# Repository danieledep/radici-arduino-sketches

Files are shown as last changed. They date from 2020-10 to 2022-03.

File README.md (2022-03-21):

# radici-arduino-sketches
arduino sketches, schematics and stl files for interactive physical audio installation

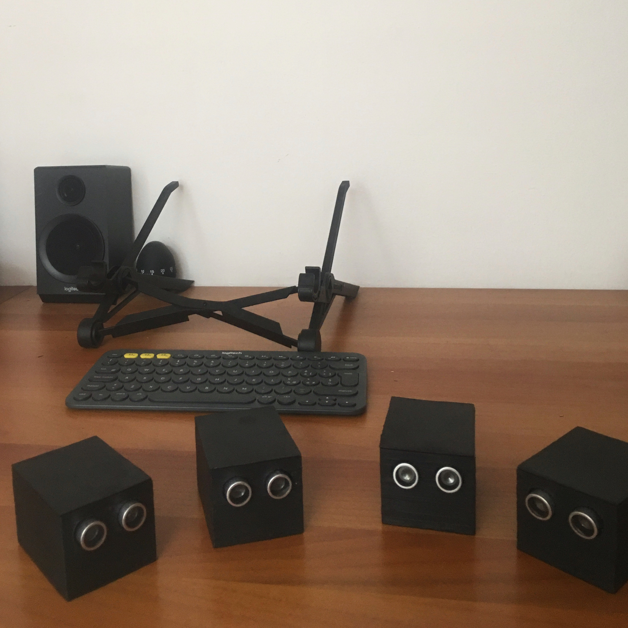
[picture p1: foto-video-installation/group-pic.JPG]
grouppic

*sensors group picture*

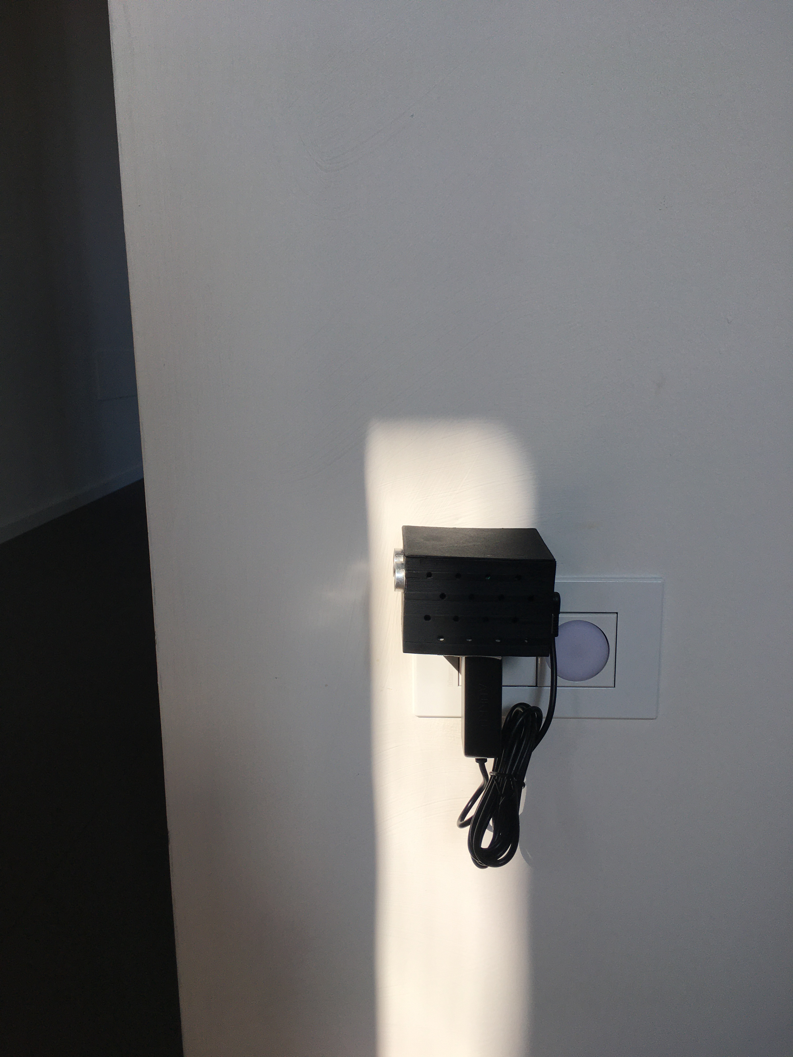
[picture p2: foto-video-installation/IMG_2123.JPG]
working sensor

*sensor at work patiently waiting for a trespass*   

The ```.wav``` sound effects are converted to data files with [wav2sketch](https://github.com/PaulStoffregen/Audio/tree/master/extras/wav2sketch) by Paul Stoffregen

## Libraries
- [RF24](https://github.com/nRF24/RF24)
- [SerialMP3Player](https://github.com/salvadorrueda/SerialMP3Player)
- [Teensy Audio Library](https://github.com/PaulStoffregen/Audio)
   
## Tutorials 
- [Getting Started with the HC-SR04 Ultrasonic sensor](https://create.arduino.cc/projecthub/Isaac100/getting-started-with-the-hc-sr04-ultrasonic-sensor-036380)
- [Simple nRF24L01+ 2.4GHz transceiver demo](https://forum.arduino.cc/index.php?topic=421081)  
- [Teensy Audio Tutorial Kit](https://www.pjrc.com/store/audio_tutorial_kit.html)
- [Instructions for using wav2sketch](https://forum.pjrc.com/threads/42401-Instructions-or-tutorials-for-using-wav2sketch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)
- [Feeding power to Arduino: the ultimate guide](https://www.open-electronics.org/the-power-of-arduino-this-unknown/)

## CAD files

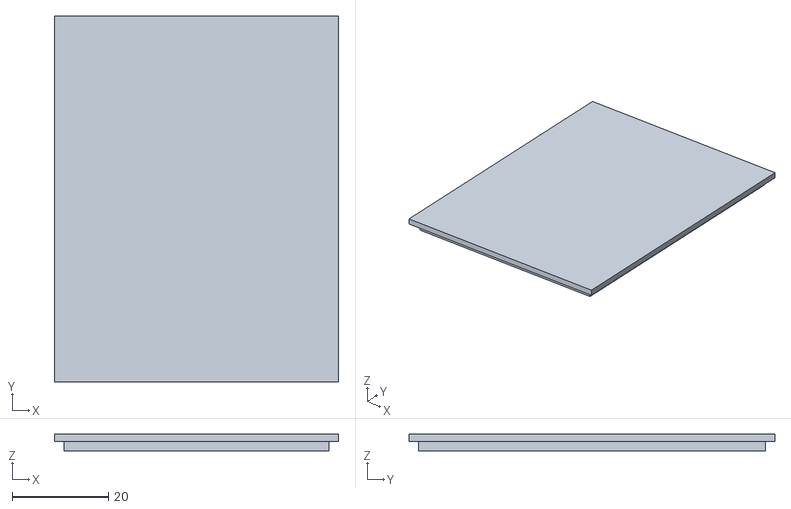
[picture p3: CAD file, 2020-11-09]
single-HCSR04-nRF24L01-tx/sensor-box-lid.stl
59.0 x 76.0 x 3.50

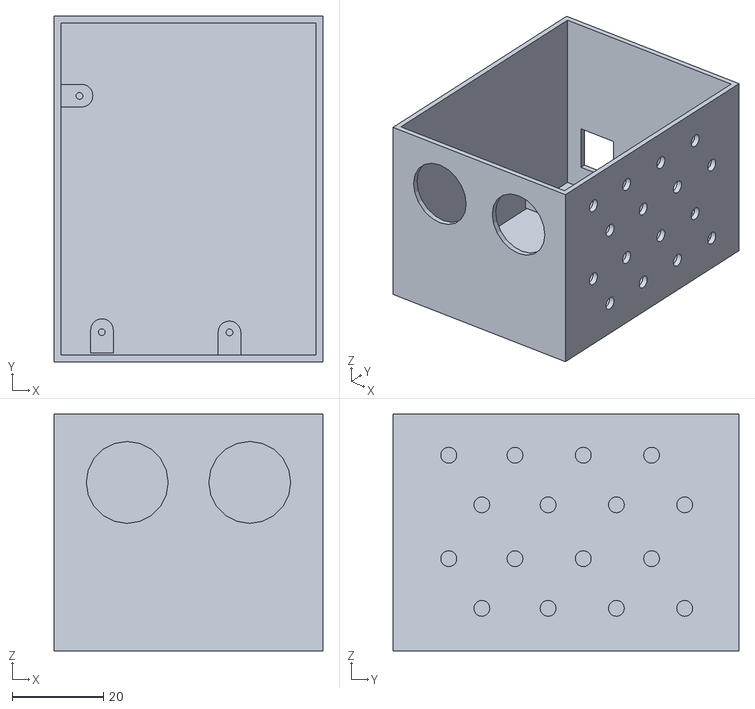
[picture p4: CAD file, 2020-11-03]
single-HCSR04-nRF24L01-tx/sensor-box.stl
59.0 x 76.0 x 52.0

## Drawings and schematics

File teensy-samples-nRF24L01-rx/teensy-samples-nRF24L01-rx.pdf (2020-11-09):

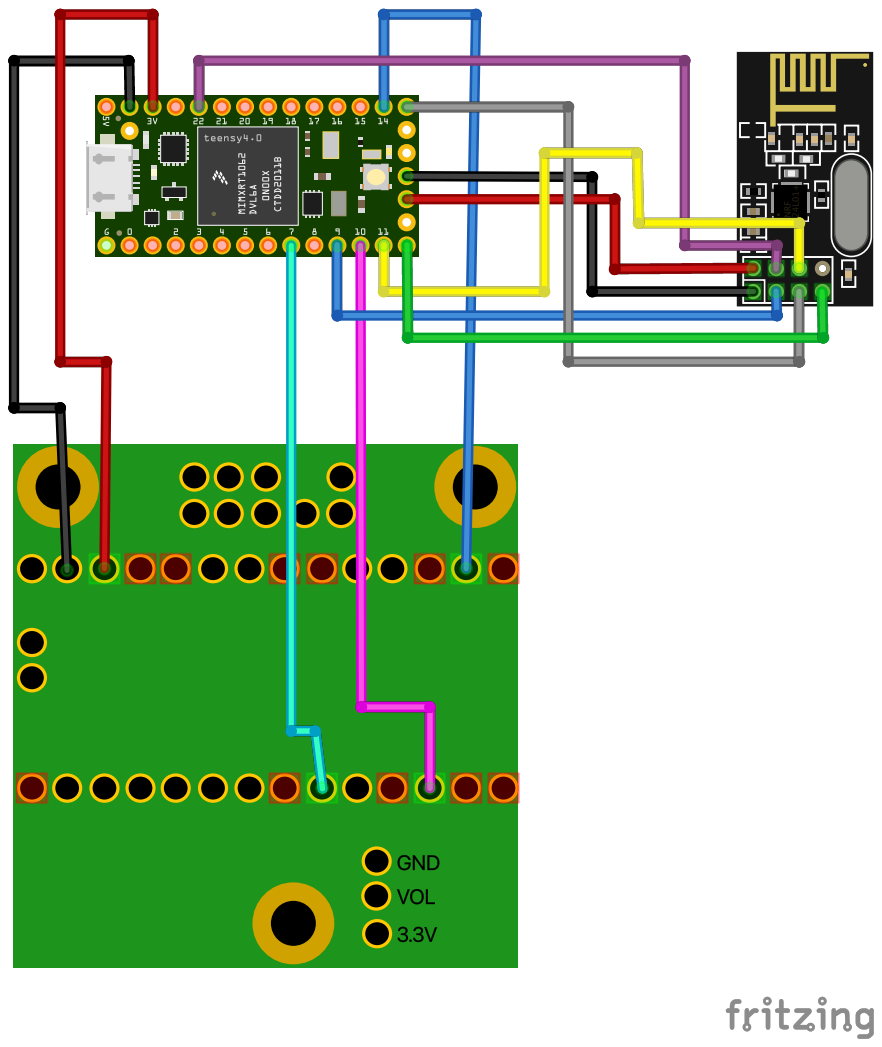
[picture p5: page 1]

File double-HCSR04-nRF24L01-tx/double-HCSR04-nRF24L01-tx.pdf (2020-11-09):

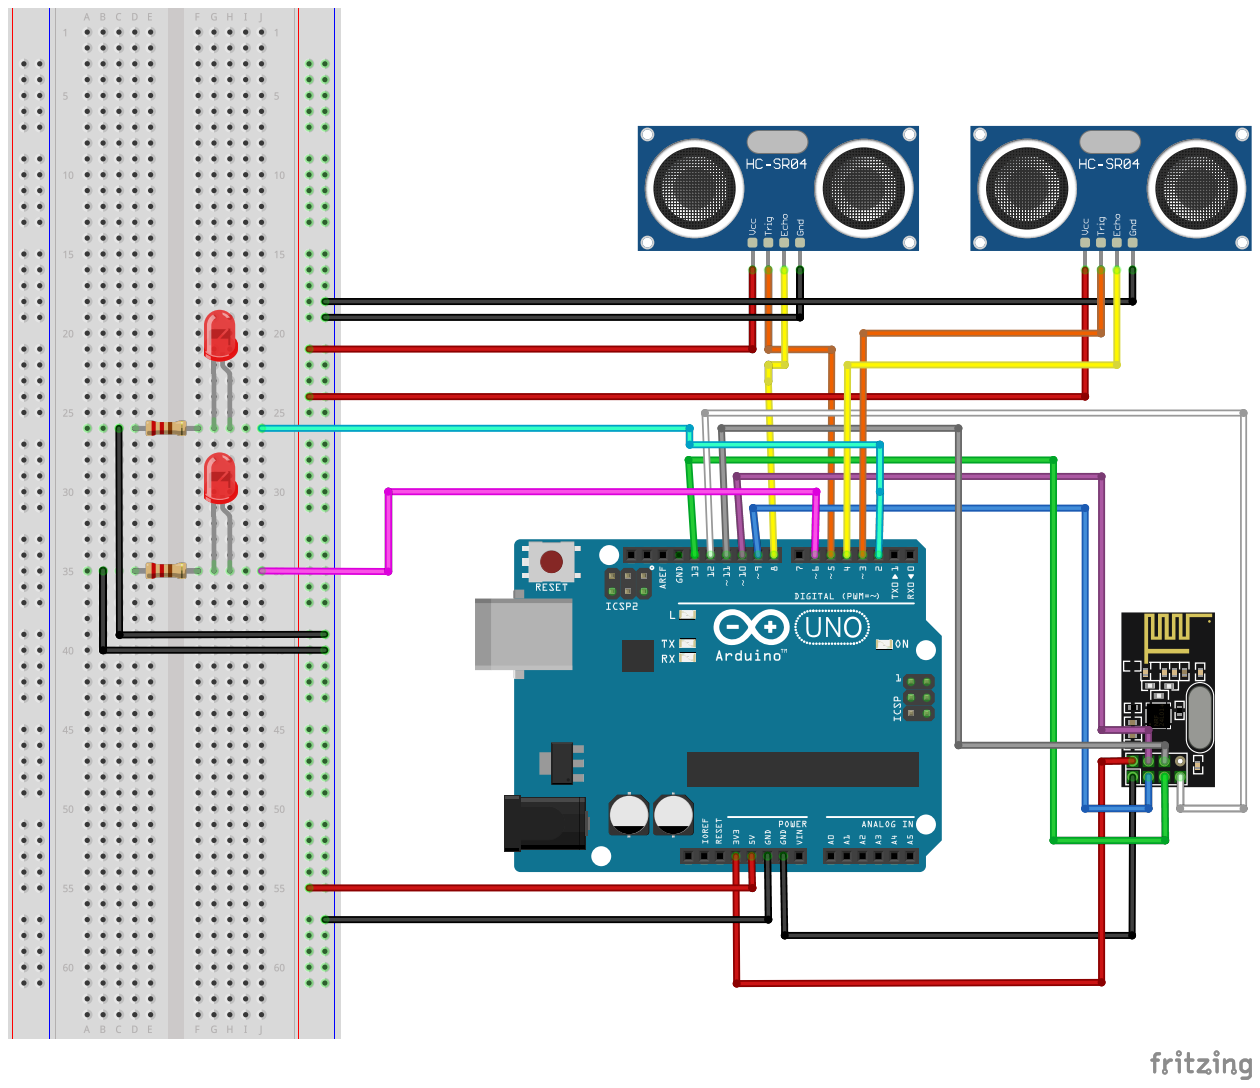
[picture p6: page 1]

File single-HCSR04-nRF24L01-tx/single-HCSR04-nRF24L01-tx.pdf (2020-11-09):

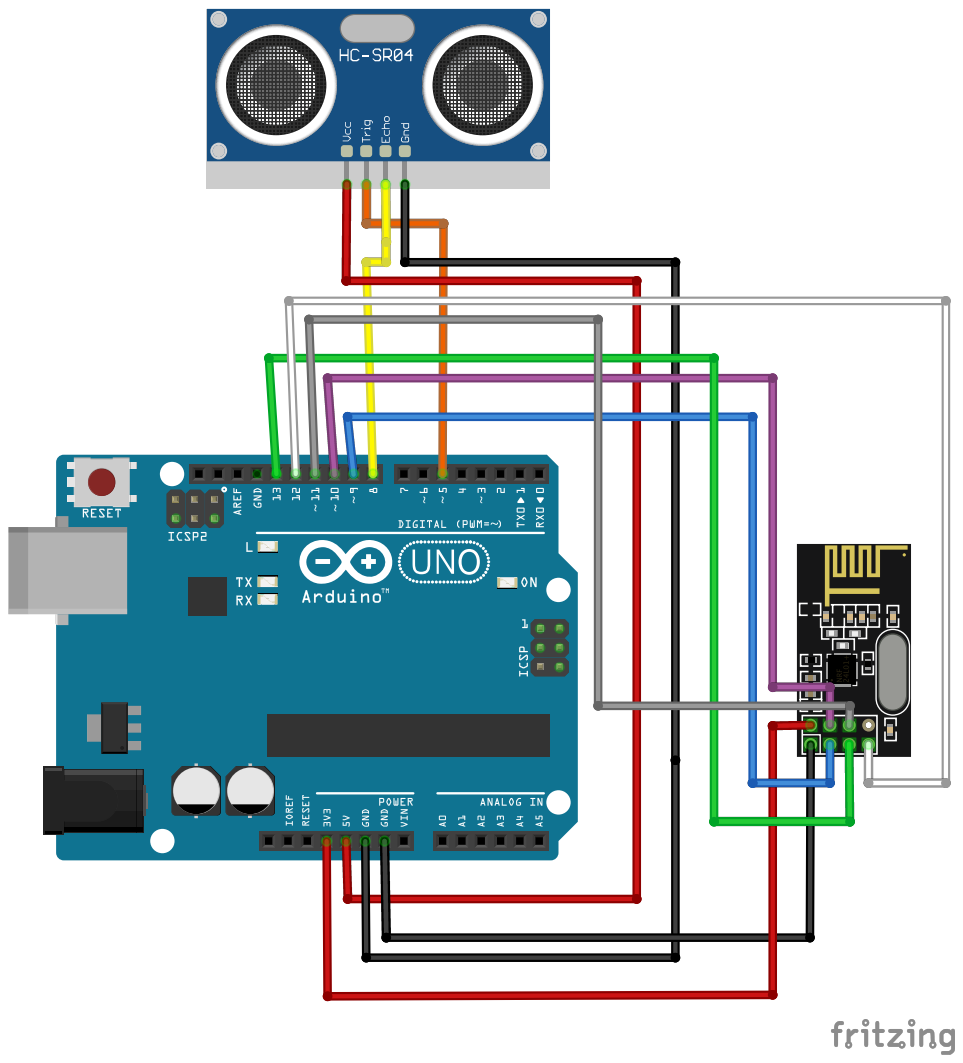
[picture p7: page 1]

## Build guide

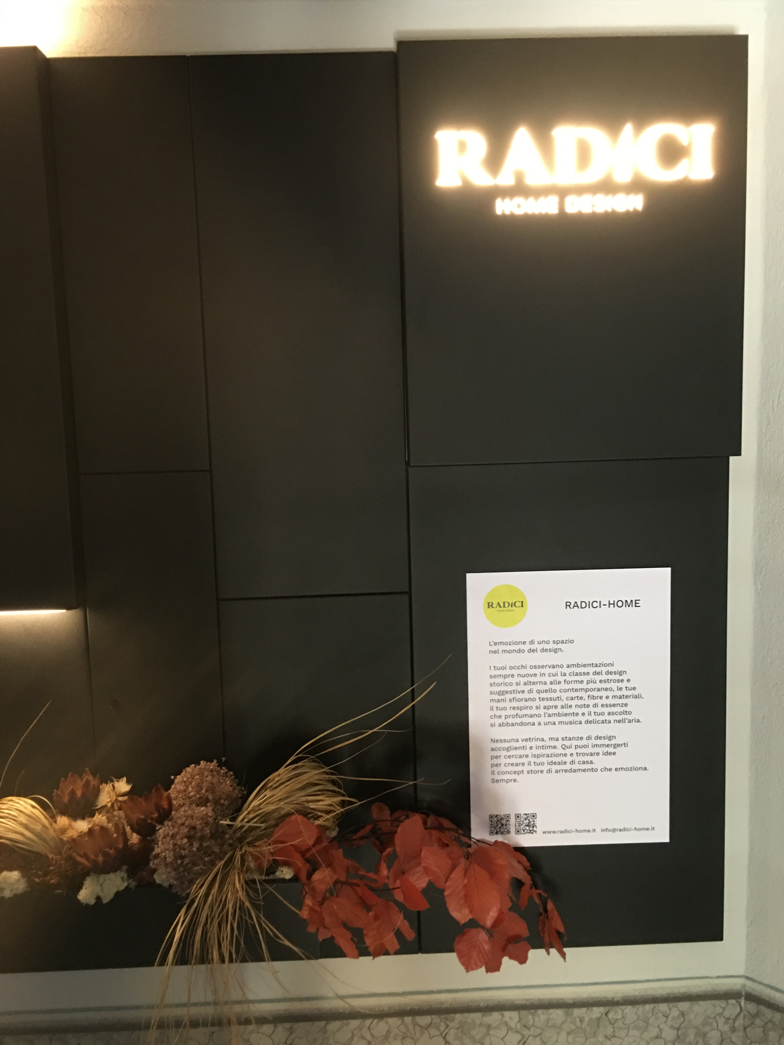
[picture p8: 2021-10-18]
foto-video-installation/IMG_2130.JPG

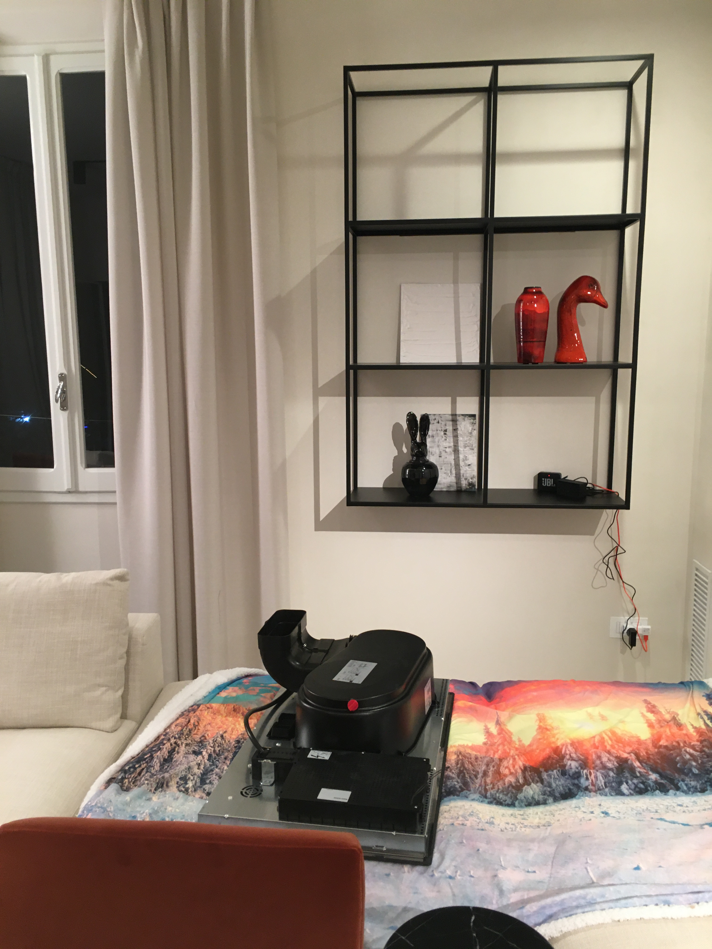
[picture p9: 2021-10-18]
foto-video-installation/IMG_2111.JPG

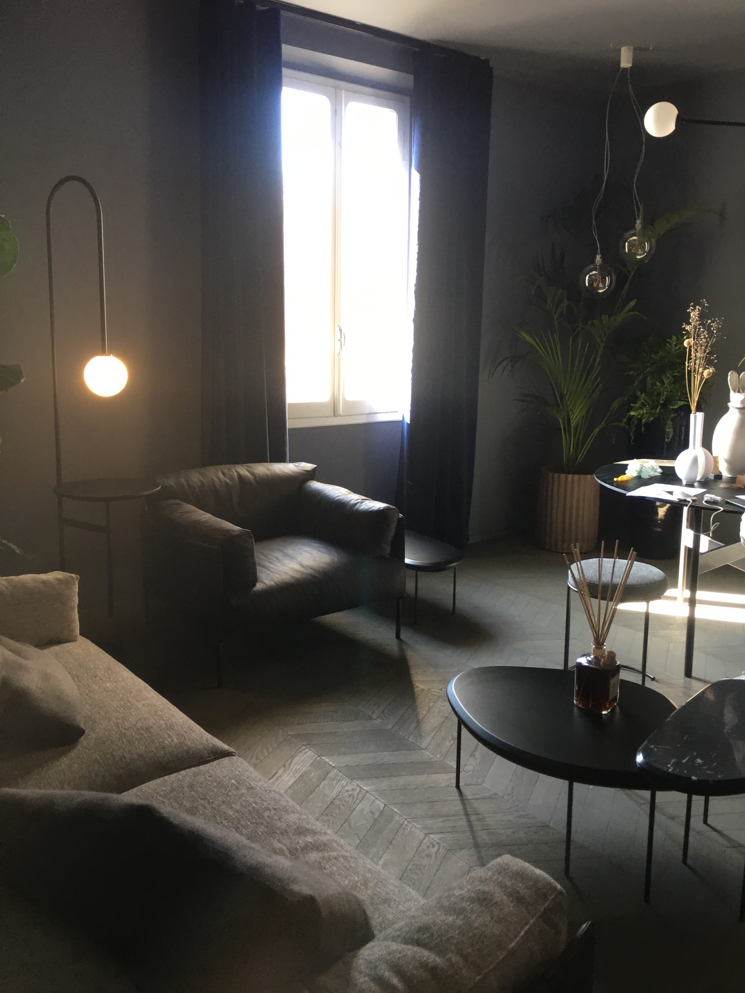
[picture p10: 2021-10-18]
foto-video-installation/IMG_2117.JPG

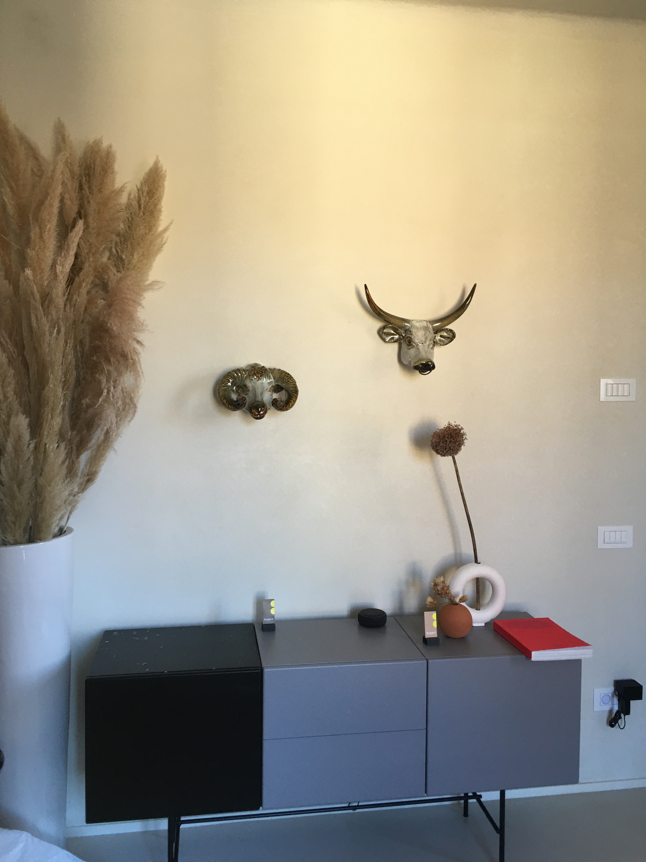
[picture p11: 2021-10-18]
foto-video-installation/IMG_2128.JPG

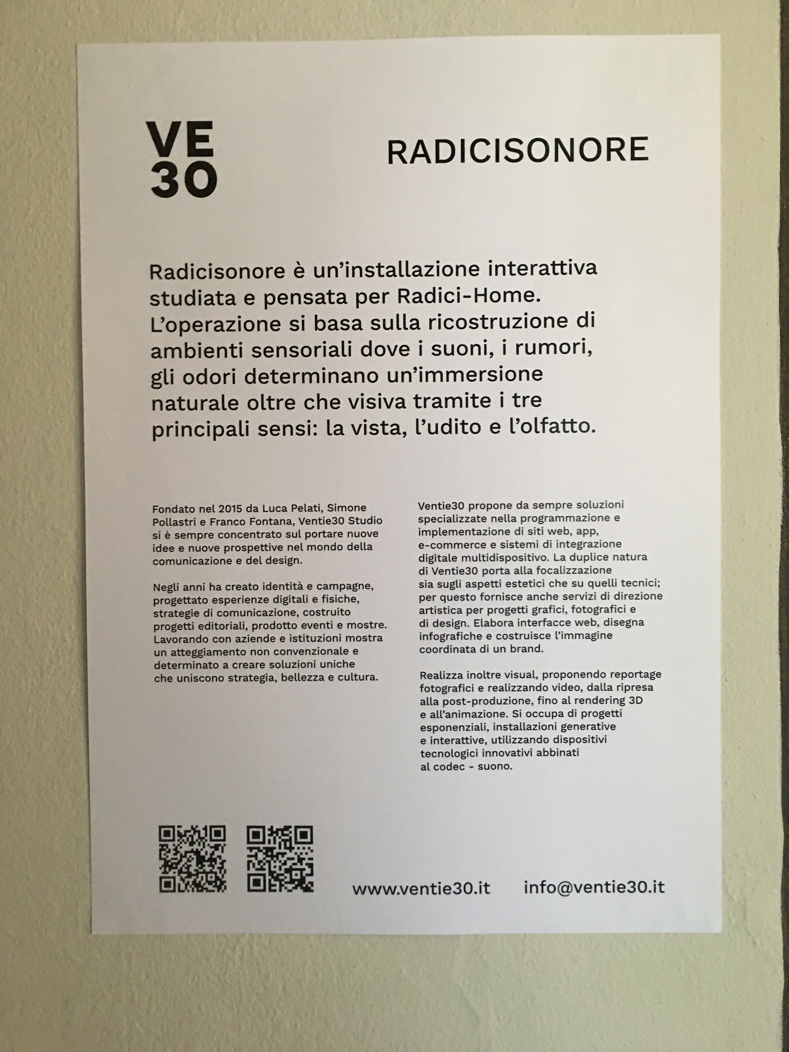
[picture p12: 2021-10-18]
foto-video-installation/IMG_2129.JPG

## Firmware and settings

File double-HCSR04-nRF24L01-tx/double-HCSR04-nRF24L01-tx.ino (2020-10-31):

#include <SPI.h>
#include <nRF24L01.h>
#include <RF24.h>


/* RADIO PINS + RADIO CHANNEL */

RF24 radio(9, 10); // CE, CSN         
const byte address[6] = "00001";     //Byte of array representing the address. This is the address where we will send the data. This should be same on the receiving side.


/* PINS DECLARATION */

const int trigPinL = 5;
const int echoPinL = 8;
const int trigPinR = 3;
const int echoPinR = 4;
const int crossPinR = 2;
const int crossPinL = 6;

/* CROSSING STATE VARIABLES */

boolean crossedL = 0;
boolean crossedR = 0;
boolean crossingL = 0;
boolean crossingR = 0;
float durationL, distanceL, durationR, distanceR;
unsigned long crossStartedL = 0;
unsigned long crossStartedR = 0;
unsigned long crossEndedL = 0;
unsigned long crossEndedR = 0;
unsigned long crossDurationL = 0;
unsigned long crossDurationR = 0;
unsigned long sinceLastCrossL = 0;
unsigned long sinceLastCrossR = 0;
unsigned long sinceCrossEndedL = 0;
unsigned long sinceCrossEndedR = 0;
boolean beenCrossedL = 0;
boolean beenCrossedR = 0;



/* SETTABLE PARAMETERS */

const int minDistance = 80;   // threshold for crossing
const int minReadTime = 100;  // minimum time for a single sensor detection to read a single crossing
const int maxWaitRead = 200;  // max time after which a cross has finished
const int maxTimeSpan = 1500; //  max time allowed to define a passage between sensors
boolean leftRight = 0; // set direction left to right, set to 0 for right to left




void setup() {
  
/* DISTANCE SENSORS SETUP */

pinMode(trigPinL, OUTPUT);
pinMode(echoPinL, INPUT);
pinMode(trigPinR, OUTPUT);
pinMode(echoPinR, INPUT);
pinMode(crossPinR, OUTPUT);
pinMode(crossPinL, OUTPUT);

/* RADIO TRANSMITTER SETUP */
radio.begin();                  //Starting the Wireless communication
radio.openWritingPipe(address); //Setting the address where we will send the data
radio.setPALevel(RF24_PA_MIN);  //You can set it as minimum or maximum depending on the distanceL between the transmitter and receiver.
radio.stopListening();          //This sets the module as transmitter
Serial.begin(9600);

}



void loop() {

  /* CALCULATE ULTRASOUND TIME OF RETURN LEFT */
  
  digitalWrite(trigPinL, LOW);
  delayMicroseconds(2);
  digitalWrite(trigPinL, HIGH);
  delayMicroseconds(10);
  digitalWrite(trigPinL, LOW);
  durationL = pulseIn(echoPinL, HIGH);
  distanceL = (durationL * .0343) / 2;

  /* CALCULATE ULTRASOUND TIME OF RETURN RIGHT */
  
  digitalWrite(trigPinR, LOW);
  delayMicroseconds(2);
  digitalWrite(trigPinR, HIGH);
  delayMicroseconds(10);
  digitalWrite(trigPinR, LOW);
  durationR = pulseIn(echoPinR, HIGH);
  distanceR = (durationR * .0343) / 2;
  
   Serial.print("L: ");
   Serial.print(distanceL);
   Serial.print(" R: ");
   Serial.print(distanceR);
   Serial.println();
  delay(10);


/* CROSSING SENSOR LEFT */

if (distanceL < minDistance)
    {
    // Serial.println("Left sensor crossed");
    crossedL = 1;
    }
else
    {
     crossedL = 0; 
    }


/* CROSS START LEFT */

if (crossedL == 1) {

  if (crossDurationL == 0) crossStartedL = millis() - 1;

  crossDurationL = millis() - crossStartedL;

  if (crossDurationL > minReadTime) {

      crossingL = 1;
      beenCrossedL = 1;
      
    }
  
}


/* CROSS END LEFT */

if (crossedL == 0 && crossingL == 1) {

  sinceLastCrossL = millis() - (crossStartedL + crossDurationL);
  
  if (sinceLastCrossL > maxWaitRead) {

    //Serial.print(" durata crossing L: ");
    //Serial.println(crossDurationL);

    crossEndedL = crossStartedL + crossDurationL;
    crossingL = 0;
    crossDurationL = 0;

  }
  
}


/* CROSSING STATE LEFT */

if ((beenCrossedL == 1) && (crossingL == 0)) {

  sinceCrossEndedL = millis() - crossEndedL;

  if (sinceCrossEndedL > maxTimeSpan) {
    
    beenCrossedL = 0;
    
  }
}


/////////////


/* CROSSING SENSOR RIGHT */

if (distanceR < minDistance)
    {
    // Serial.println("Left sensor crossed");
    crossedR = 1;
    }
else
    {
     crossedR = 0; 
    }


/* CROSS START RIGHT */

if (crossedR == 1) {

  if (crossDurationR == 0) crossStartedR = millis() - 1;

  crossDurationR = millis() - crossStartedR;

  if (crossDurationR > minReadTime) {

      crossingR = 1;
      beenCrossedR = 1;
      
    }
  
}


/* CROSS END RIGHT */

if (crossedR == 0 && crossingR == 1) {

  sinceLastCrossR = millis() - (crossStartedR + crossDurationR);
  
  if (sinceLastCrossR > maxWaitRead) {

    //Serial.print(" durata crossing R: ");
    //Serial.println(crossDurationR);

    crossEndedR = crossStartedR + crossDurationR;
    crossingR = 0;
    crossDurationR = 0;

  }
  
  
}

/* CROSSING STATE RIGHT */

if ((beenCrossedR == 1) && (crossingR == 0)) {

  sinceCrossEndedR = millis() - crossEndedR;

  if (sinceCrossEndedR > maxTimeSpan) {
    
    beenCrossedR = 0;
    
  }
}


digitalWrite(crossPinL, beenCrossedL);
digitalWrite(crossPinR, beenCrossedR);

////////

if (beenCrossedL == 1 && beenCrossedR == 1) {
  
  if (crossStartedL > crossStartedR) {

     Serial.println();
    Serial.println();
    Serial.println();
    Serial.println();
    Serial.println("crossed from right to left");
    if (leftRight == 0) 
        radio.write(&beenCrossedL, sizeof(beenCrossedL));  //Sending the sensor state to receiver 
    
  } 

  if (crossStartedR > crossStartedL) {

    Serial.println();
    Serial.println();
    Serial.println();
    Serial.println();
    Serial.println("crossed from left to right");
    if (leftRight == 1) 
        radio.write(&beenCrossedR, sizeof(beenCrossedR));  //Sending the sensor state to receiver 
    
  }

  delay(100);
   beenCrossedL = 0;
    beenCrossedR = 0;

  boolean endSignal = 0;
  radio.write(&endSignal, sizeof(endSignal));  //Sending the sensor state to receiver 
  
}


}

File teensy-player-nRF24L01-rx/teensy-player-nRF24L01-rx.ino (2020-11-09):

// Simple WAV file player example
//
// Three types of output may be used, by configuring the code below.
//
//   1: Digital I2S - Normally used with the audio shield:
//         http://www.pjrc.com/store/teensy3_audio.html
//
//   2: Digital S/PDIF - Connect pin 22 to a S/PDIF transmitter
//         https://www.oshpark.com/shared_projects/KcDBKHta
//
//   3: Analog DAC - Connect the DAC pin to an amplified speaker
//         http://www.pjrc.com/teensy/gui/?info=AudioOutputAnalog
//
// To configure the output type, first uncomment one of the three
// output objects.  If not using the audio shield, comment out
// the sgtl5000_1 lines in setup(), so it does not wait forever
// trying to configure the SGTL5000 codec chip.
//
// The SD card may connect to different pins, depending on the
// hardware you are using.  Uncomment or configure the SD card
// pins to match your hardware.
//
// Data files to put on your SD card can be downloaded here:
//   http://www.pjrc.com/teensy/td_libs_AudioDataFiles.html
//
// This example code is in the public domain.


// nRF24L01 Libraries
#include <SPI.h>
#include <RF24.h>

// Audio libraries
#include <Audio.h>
#include <Wire.h>
#include <SD.h>
#include <SerialFlash.h>

AudioPlaySdWav           playWav1;
// Use one of these 3 output types: Digital I2S, Digital S/PDIF, or Analog DAC
AudioOutputI2S           audioOutput;
//AudioOutputSPDIF       audioOutput;
//AudioOutputAnalog      audioOutput;
AudioConnection          patchCord1(playWav1, 0, audioOutput, 0);
AudioConnection          patchCord2(playWav1, 1, audioOutput, 1);
AudioControlSGTL5000     sgtl5000_1;

// Use these with the Teensy Audio Shield
#define SDCARD_CS_PIN    10
#define SDCARD_MOSI_PIN  7
#define SDCARD_SCK_PIN   14

// Use these with the Teensy 3.5 & 3.6 SD card
//#define SDCARD_CS_PIN    BUILTIN_SDCARD
//#define SDCARD_MOSI_PIN  11  // not actually used
//#define SDCARD_SCK_PIN   13  // not actually used

// Use these for the SD+Wiz820 or other adaptors
//#define SDCARD_CS_PIN    4
//#define SDCARD_MOSI_PIN  11
//#define SDCARD_SCK_PIN   13


// RF24 radio(9, 10); // Original CSN pin in conflict with MicroSD SCN pin 
RF24 radio(9, 22); // CE, CSN
const byte address[6] = "00001";
boolean crossed = 0; 

void setup() {
  Serial.begin(9600);

  // Audio connections require memory to work.  For more
  // detailed information, see the MemoryAndCpuUsage example
  AudioMemory(8);

  // Comment these out if not using the audio adaptor board.
  // This may wait forever if the SDA & SCL pins lack
  // pullup resistors
  sgtl5000_1.enable();
  sgtl5000_1.volume(1.0);


  Serial.begin(115200);
  //while (!Serial);
  radio.begin();
  radio.setDataRate( RF24_250KBPS );
  radio.setChannel( 90 );
  radio.openReadingPipe(0, address);
  radio.printDetails();
  radio.setPALevel(RF24_PA_MIN);
  radio.startListening();
  Serial.println( "Ready" );

  
  SPI.setMOSI(SDCARD_MOSI_PIN);
  SPI.setSCK(SDCARD_SCK_PIN);
  if (!(SD.begin(SDCARD_CS_PIN))) {
    // stop here, but print a message repetitively
    while (1) {
      Serial.println("Unable to access the SD card");
      delay(500);
    }
  }
}

void playFile(const char *filename)
{
  Serial.print("Playing file: ");
  Serial.println(filename);

  // Start playing the file.  This sketch continues to
  // run while the file plays.
  playWav1.play(filename);

  // A brief delay for the library read WAV info
  delay(5);

  // Simply wait for the file to finish playing.
  while (playWav1.isPlaying()) {
    // uncomment these lines if you audio shield
    // has the optional volume pot soldered
    //float vol = analogRead(15);
    //vol = vol / 1024;
    // sgtl5000_1.volume(vol);
  }
}


void loop() {

   if (radio.available()) {
  //char text[32] = "";
  //radio.read(&text, sizeof(text));
  radio.read(&crossed, sizeof(crossed));
  Serial.print( "[" );
  Serial.print( crossed);
  Serial.println( "]" );

  if (crossed == 1) {


      playFile("SDO1.WAV");
      delay(500);

      crossed = 0;

    
  } // End if crossed == 1 

  } // End if radio 

} // End void loop()
